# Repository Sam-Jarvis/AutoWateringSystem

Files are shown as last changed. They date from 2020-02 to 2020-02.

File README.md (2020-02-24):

# AutoWateringSystem
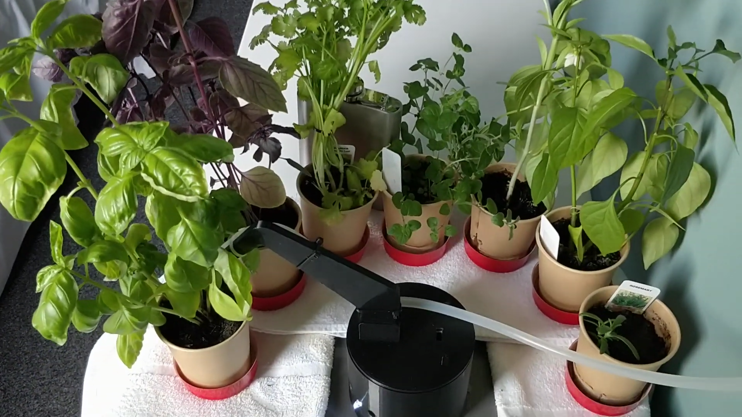
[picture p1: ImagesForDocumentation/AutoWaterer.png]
Image of msn-lsn
<br>
__Video example:__ https://youtu.be/DMxAB1ufoSI<br>

### This repository contains 3D designs, code and a technical report of an automatic plant watering system I built.<br>

The system is designed and built to be run on an arduino, thus it is programmed in C using the Arduino IDE. The purpose of the system is to water herbs or other plants without human interaction. This is based on a timer that can be set by the user. The system can water a set number of plants or it can adapt to the number of plants on the fly given that an ultrasonic sensor is connected.<br>

The parts necessary to build the system are:
* Servo (small)
* Arduino
* Jumper wires
* Ultrasonic sensor (_optional_)
* 9V battery
* Relay
* Aquarium pump

Details of the project can be found in the technical report but to summarize the system, the relay control an aquarium pump that is placed in a reservoir of water. The relay is controlled by the Arduino which is powered by the 9V battery. The time interval between watering is set using the potentiometer.<br>  

The parts are assembled inside the 3D printed base and connected together like this (also in the technical report):
### Circuit Diagram
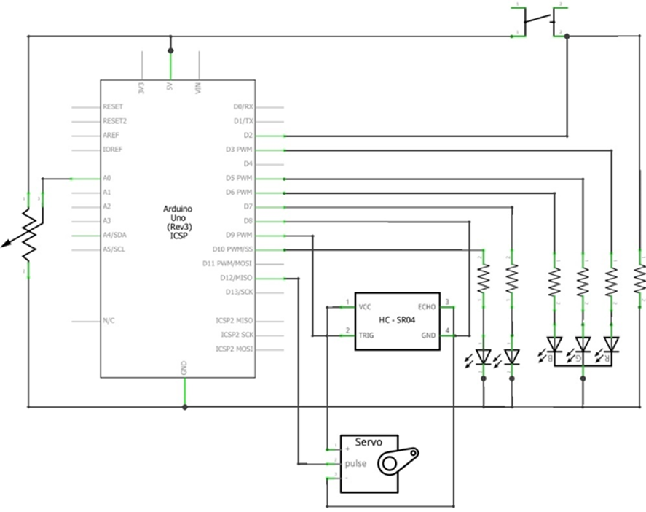
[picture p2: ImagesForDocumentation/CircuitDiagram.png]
Image of msn-lsn
<br>

### Example Circuit
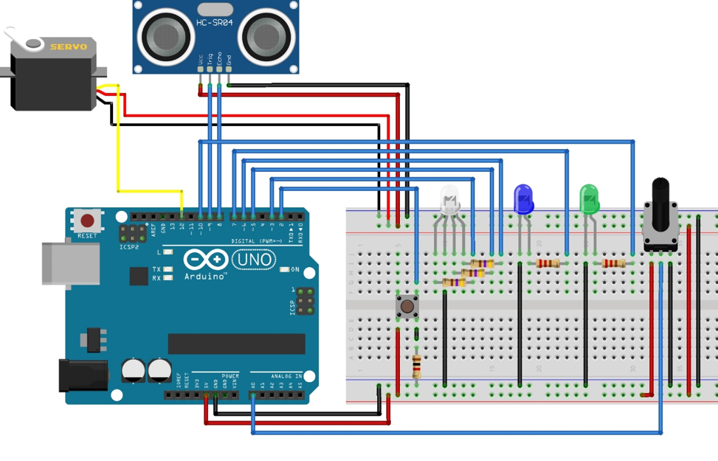
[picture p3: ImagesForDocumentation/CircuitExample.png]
Image of msn-lsn
<br>

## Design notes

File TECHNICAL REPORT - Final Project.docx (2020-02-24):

TECHNICAL REPORT

Auto-Watering System

Embedded Systems (ES1)

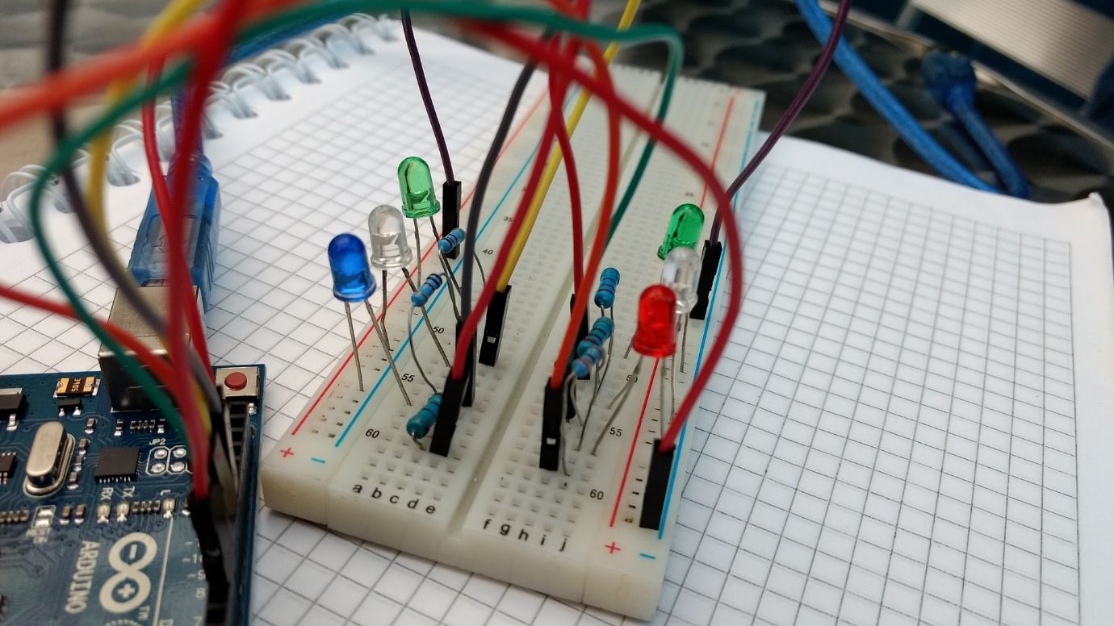
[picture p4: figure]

LECTURER: Gerald Hilderink

DATE: 29-03-2019

AUTHORS: Sam Jarvis - 3734811

Yasser Alhazmi - 405156

Abstract

The week 6 assignment proved more flexible than previous weeks which presented different problems. The goal of the final assignment was to use as many of the components from previous weeks as possible. An auto-watering system was constructed using the following parts: one button, two LEDs, one RGB LED, one potentiometer, one servo and one ultrasonic sensor. Some of the techniques learned were LEDs, buttons, button debounce, potentiometer, RGB, functions, correct scoping, state machines, serial communication, Servo, and ultrasonic sensor.

# Introduction

The auto watering system is the product of the week 6 final assignment. The aim of the assignment was to use as many of the components that featured in previous assignments, as possible. However, the practical purpose of the auto-watering system is to solve a real-world problem. The auto-watering system tends to pot plants with minimal user interaction. This means the user can configure the system as they desire and have little to no interaction with the system thereafter. The problem this system solves is neglection of plants due to more important day-to-day activities.

The system works as follows. When the power button is pressed, the system turns on. A green LED illuminates to visually represent this. If the system is on and the power button is held down, the system and LED turn off. Once on, the arm rotates from 0 degrees to 180 degrees at intervals of 20 degrees. At each iteration, it tries to detect a plant. If a plant is detected, the arm stops rotating, and the blue LED illuminates to simulate the system watering a plant. Once it has repeated this and watered all plants in a semicircle, the system waits for a user selected time. The use can determine this time by changing the value of a potentiometer. If the time is two hours, the system will wait at 180 degrees for two hours before repeating the cycle in reverse. The user selected time is illustrated by an RGB LED. The LED will cycle the RGB spectrum for the user selected time. For example, if the user selected time is two hours, the RGB LED will take two hours to cycle from green to red.

## Procedure

### Apparatus

- 1x breadboard
- 19x male-to-male jumper wires
- 1x Arduino Uno
- 2x LEDs
- 1x RGB LED
- 5x 470-ohm resistor
- 1x button
- 1 x 10kΩ resistor
- 1x potentiometer 1kΩ
- 1x ping sensor
- 1x servo
- 1x 3D printed design

Before starting the assignment, it was necessary to test all the apparatus separately to make sure all hardware was working as expected. To do this, a multimeter was set to the correct mode and connected across each component so that if there was a current present, it would flow through the component and the multimeter. If the multimeter made a beep noise, the component was declared working and was used in the system.

The procedure of this plant watering device is complex. The simplest approach to describe it is to follow the program beginning-to-end. The program begins by including the servo library[^1] and by following the conventions of the C programming language by defining functions above main. It then continues to declare and initialize the constant and global variables of the program. Pins are declared using the “const int” approach rather than the pre-processor directive “#define” because the former is the advised method according to the Arduino programming reference [[^2]]. The servo object is also declared as a global variable. It will be accessed by multiple methods in the program. In the “setup()”[^3] method, all pins were assigned an appropriate mode using the “pinMode()”[^4] method. In addition to this, the servo was attached to the appropriate pin using “Servo.attach()”[^5] method, and serial communication was initiated using “Serial.begin()”[^6]with the default baud rate of 9600.

The machine then enters the “loop()”[^7] method while still in turned off state. In the loop, the program checks whether the button is clicked. This check includes a button debounce function of 70 milliseconds to eliminate any possible bouncing effect. If the button is clicked, the method “turnMachine()” is called to turn the machine on. The method “turnMachine()” will check the “machineIsOn” variable status. If machine is off, the following steps are taken to turn the machine on:

1. Turn the green LED on.
2. Read the potentiometer value. This is to ensure persistence, that is, the user is not required to input the time interval each time the system is started. The value is mapped to hours and saved as a time interval that is later used as a delay.
3. Print that the machine is turned on via serial communication.
4. Change the machineIsOn variable to true.

After the machine is turned on, the program continues to the loop() method. A “while” loop is initiated if machineIsOn is equal to true. In the while loop, the method rotateServo() is called to rotate the servo. This method will start with angle of 0 degrees and rotate by 20 degrees each time the method is called. This is done by calling the servo.write()[^8] method from the servo library and supplying the angle to it as an argument.

After each call (a rotation of 20 degrees has occurred), it calls the method detectPlant() to determine whether the ultrasonic can detect an object (plant). The detectPlant() method uses the ultrasonic sensor to detect an object within the appropriate distance. This code was re-used from a previous assignment[^9]. Based on the 3D design, the appropriate distance for a plant is 4-6 centimetres from the system. If a plant is detected within this distance, the servo will temporarily stop rotating to allow the system to water the plant. The blue LED will turn on to simulate watering.

When the servo reaches an angle of 180 degrees, that is, it’s maximum, it will stop for a certain amount of time before repeating the cycle in reverse. This is done by calling the method delayWatering(). The same method is called when the servo rotates back to an angle of 0, that is, it’s minimum. The amount of delay time between cycles is changed as follows:

1. The initial value of the potentiometer is read and mapped to a time in milliseconds when the device is turned on.
2. The current value of the potentiometer is read after each servo rotation in case the user changes the state of the potentiometer.
3. If the current value is equal to initial value, no action is taken.
4. If the current value is not equal to initial value, the initial value is changed to the current value.
5. This value is used as the amount of time to wait between watering cycles.

To convert the value read from the potentiometer to a value of time in milliseconds, the following steps are taken:

1. The potentiometer reading is mapped from a value between 0 and 1023, to a value between 1 and 12. Thus, the user can specify a time interval between 1-12 hours to wait in between each watering cycle.
2. The mapped value is converted to milliseconds by the equation: delayTime = mappedValue * 60 * 60 * 1000. To further explain, a value between 1 and 12 is multiplied by 60 to convert it from hours to minutes. This is converted to seconds by multiplying by 60 again and finally, it is multiplied by 1000 to convert it to milliseconds. The reason for this is so that the native “delay()” method can be used.
3. To cycle through the RGB spectrum (from green to red) while waiting, the delay time is divided by the number of values in the spectrum (256 to include the 0). This provides the delay in milliseconds that the Arduino must wait before changing the RBG value. This is done in a method called “delayWatering()”.

The “delayWatering()” method will initialize the green colour channel of the RGB LED to 255 and red, blue, and counter to zero, because it will only cycle the spectrum after watering is finished. After the appropriate delay, green will decrease by one, red will increase by one, and counter will increase by one as well. The method “changeRgbByValue()” is re-used from a previous assignment, and it changes the value of an RGB LED based on three integers values red, green, and blue. The method loops until the counter reaches 255. At this point, red will be 255 and green will be zero. The loop will terminate because the delay time has ended, and the system will induce another cycle. That is, the servo will start rotating to water the plants again.

# Design and Construction

The system consists of three main parts namely, the physical body, the circuit and electronics and the software written in C. Each of these categories has a design aspect which is described in detail below.

## Body

The body of the system was specific to its purpose and thus had specific requirements. For example, the upper section had to rotate using the servo. So, the upper section needed a bed for the servo rudder to rest in. For this reason, the parts were designed using measurements from the electronic components and 3D printed.

The body consisted of the following parts:

1. The base.

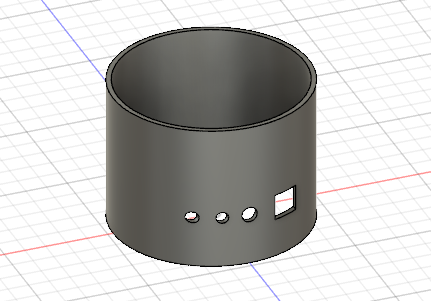
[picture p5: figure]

Figure 1 illustrates the 3D design of the base. This is the container for the system and has the required fittings for the potentiometer, two LEDs and the button. This is the biggest component because it is the structural integrity of the system.

2. The Lid

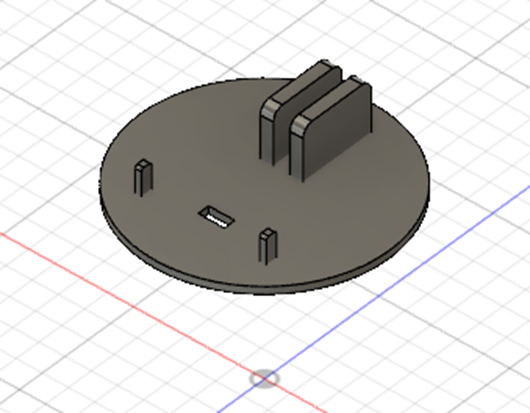
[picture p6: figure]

Figure 2 illustrates the lid of the system. The lid is the component between the solid foundation and the rotating section of the system. The lid has fittings designed for the ultrasonic sensor. It has a bay for the ultrasonic sensor to rest in as well has a space for its wires to connect through.

3. The Arm

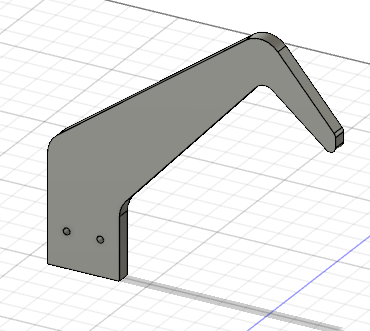
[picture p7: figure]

Figure 3 illustrates the arm. This connects to the lid and is responsible for watering the plants. The arm has two screw holes to secure it to the lid.

4. The Servo Bay

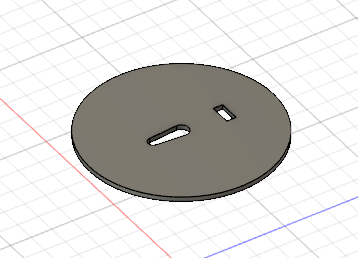
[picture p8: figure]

Figure 4 illustrates the servo bay. This component is responsible for attaching the lid to the base such that the lid can rotate whilst the base does not. It has fittings for the servo rudder and a space for the ultrasonic sensor wires. It is fixed to the underside of the lid such that the space for the ultrasonic sensor wire align.

## Circuit

The circuit represents the electrical components and how they are connected to the Arduino. The Schematic diagram of the circuit can be found below.

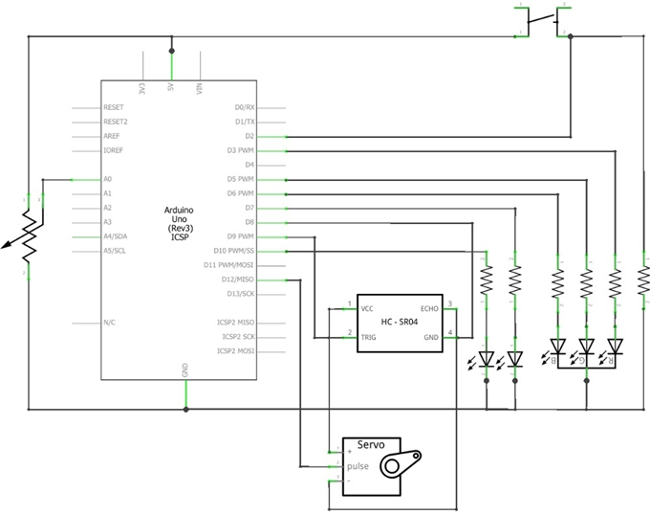
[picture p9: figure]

Figure 5 illustrates how the components are connected to the Arduino. All components have a live and ground connection. Each RGB channel is connected to a separate pin. The servo is connected to pin 12, the ultrasonic sensor is connected to pins 8 and 9, the potentiometer is connected to pin A0, the normal LEDs are connected to pins 10 and 7 and finally, the RGB LED is connected to pins 3, 5 and 6.

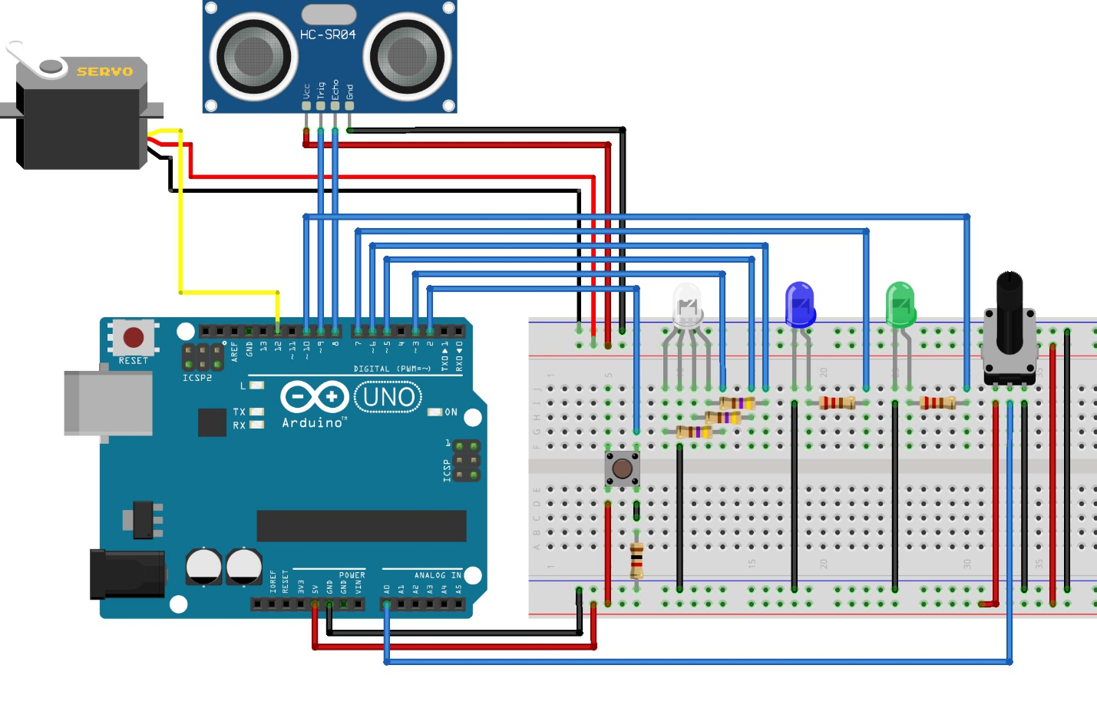
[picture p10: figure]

Figure 6 illustrates a graphical example of the components connected to the Arduino.

## Software

The software aspect of the system features under the design section due to the state machine ideology that is embedded within it. Each function that the system offers is a separate state in the software. For example, when the Arduino is plugged in, but the power button has not been pressed, it is in the “turned off” state.

The state diagram of the system is presented below:

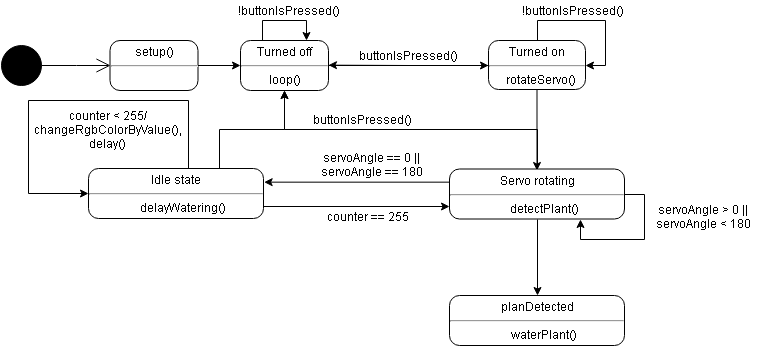
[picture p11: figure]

Figure 7 describes the state machine of the system. On initialization, the system is in the turned off state. When the power button is pressed, the state is changed to “Turned On”. From the “Turned On” state, the system proceeds to the “Servo Rotating” state, unless the user presses the power button. In this case, the state is changed to “Turned Off”. In the “Servo Rotating” state, the system will proceed into the “Plant Detected” state if a plant is detected. If no plant is detected, the system remains ins the “Servo Rotating state” if the servo angle is less than 180 degrees. Once this condition is false, the system will move into the “Idle” state where it will remain until the counter is 256. At this point it will return to the “Servo Rotating” state. It is also possible for the system to go from the Idle state to the “Turned Off” state should the user press the power button.

# References

Some of the components and techniques used required some research first. Below is a list of all the resources used to complete this assignment.

[^1] https://www.arduino.cc/en/Reference/Servo
[^2] https://www.arduino.cc/reference/en/language/structure/further-syntax/define/
[^3] https://www.arduino.cc/reference/en/language/structure/sketch/setup/
[^4] https://www.arduino.cc/reference/en/language/functions/digital-io/pinmode/
[^5] https://www.arduino.cc/en/Reference/ServoAttach
[^6] https://www.arduino.cc/en/serial/begin
[^7] https://www.arduino.cc/en/Reference/Loop (https://www.arduino.cc/en/Reference/Loop?setlang=it)
[^8] https://www.arduino.cc/en/Reference/ServoWrite
[^9] http://www.robot-electronics.co.uk/htm/arduino_examples.htm#SRF04%20Ultrasonic%20Ranger 10 https://www.youtube.com/watch?v=_B3gWd3A_SI&t=95s

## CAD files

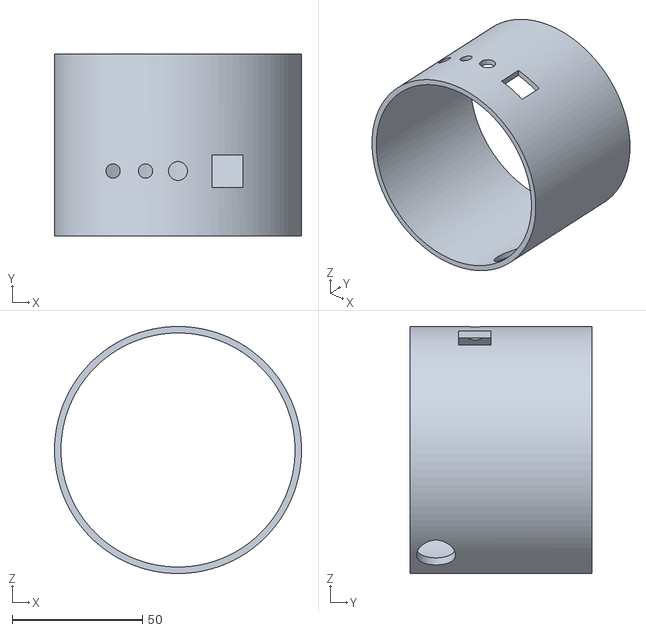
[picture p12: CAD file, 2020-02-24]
3D designs/base.stl
95.0 x 70.0 x 95.0

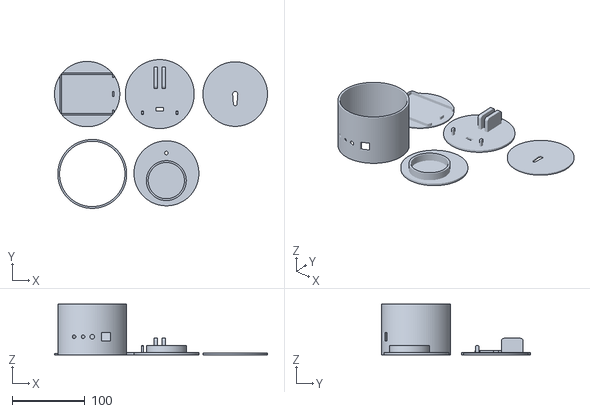
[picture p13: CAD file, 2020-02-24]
3D designs/ES1_Week6_Version3.stl
293.5 x 205.0 x 70.0

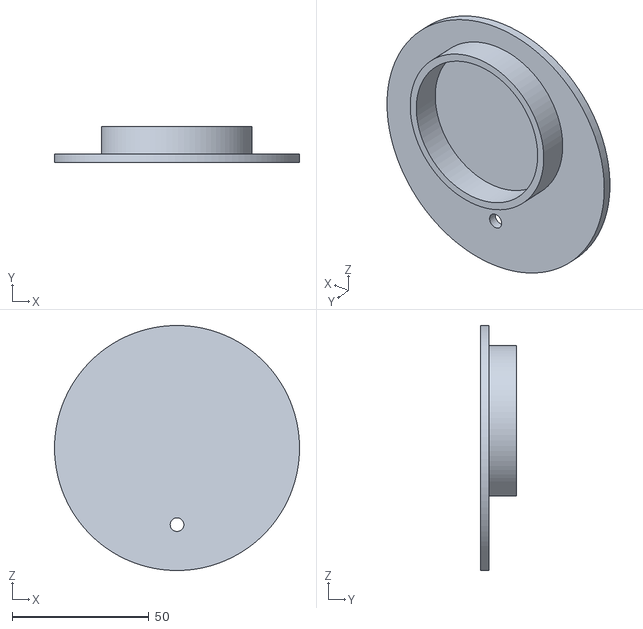
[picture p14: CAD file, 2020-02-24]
3D designs/servo_base.stl
89.5 x 13.0 x 89.5

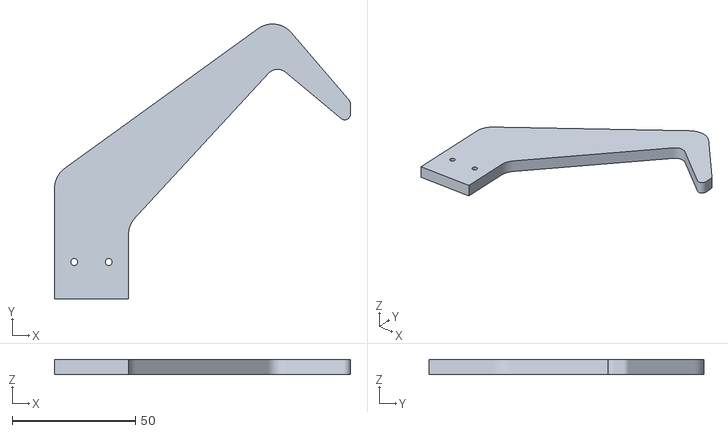
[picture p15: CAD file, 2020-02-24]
3D designs/arm.stl
120.0 x 111.5 x 6.00

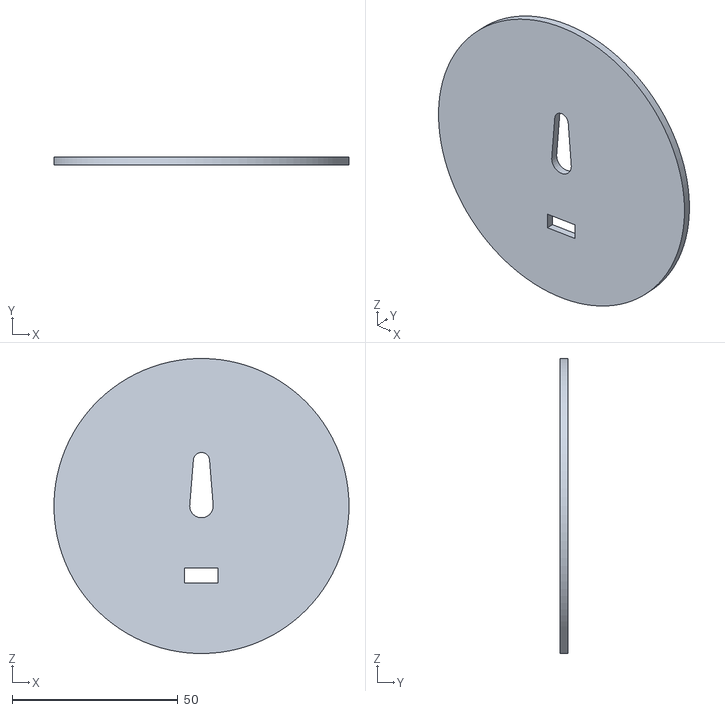
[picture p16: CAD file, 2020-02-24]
3D designs/servo_bay.stl
89.0 x 2.30 x 89.0

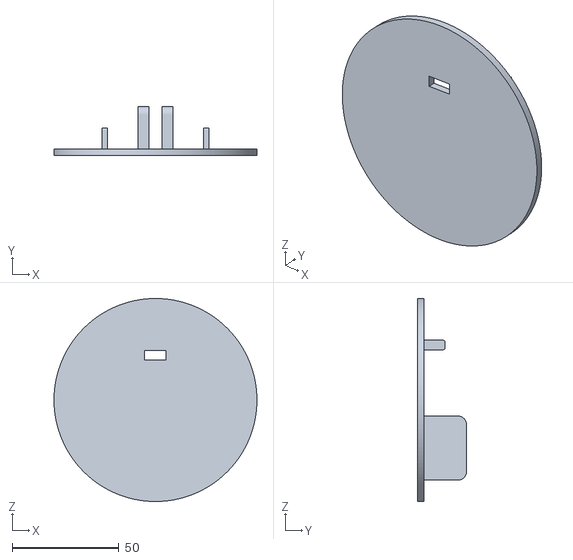
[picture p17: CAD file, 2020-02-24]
3D designs/lid.stl
95.0 x 23.0 x 95.0

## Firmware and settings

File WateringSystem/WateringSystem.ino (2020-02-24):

/*********************************************************
* ES1 Week 6 and 7 Assignment
*
* Course : Embedded Systems 1 (ES1)
* Assignment: ES1 Final Project Assignment
* Date : 1-04-2019
* Student(s) : Sam Jarvis (3734811)
*              Alhazmi Yasser (3529495)
*
*********************************************************/
#include <Servo.h>

/*** Function declarations ***/

//Turn the machine on or off based on the boolean machineIsOn
void turnMachine();

//Button debounce that takes the button pin number and debounce time in milliseconds as arguments
boolean buttonIsPressed(int, int);

//Rotate the servo and with every rotation invoke detectPlant()
void rotateServo();

//Use PING to detect if a plant exist
void detectPlant();

//Check if the user changed the watering time interval and set the new interval if necessary
void checkTimeInterval(int);

//Convert the potentiometer mapped value to milliseconds
long int hourToMilliSeconds(int);

//Change the RGB LED color based on passed value
void changeRgbColorByValue(int, int, int)

/*** PINS and Program Constants ***/
//Potentiometer PIN
const int POTENTIOMETERPIN = A0;

//Button pin
const int BUTTONPIN = 2;

// Blue channel pin (on the LED)
const int BLUEPIN = 6;

// Green channel pin (on the LED)
const int GREENPIN = 5;

// Red channel pin (on the LED)
const int REDPIN = 3;

//LED Pins
const int LEDPINHIGH = 10;
const int WATERINGLED = 7;

//Servo pin
const int SERVOPIN = 12;

//Ping ECHO pin
const int ECHOPIN = 8;

//Ping TRIGGER pin
const int TRIGPIN = 9;

//debounce time for the debounce functions
const int debounceTime = 70;

/*** Global variables ***/

//To determine the machine state
boolean machineIsOn;

//Time to wait after one watering round
int timeInterval;

//Servo object to control the servo
Servo myservo; 


void setup() {
  //LEDs, button, and potentiometer are set to the appropriate pinMode
  pinMode(BUTTONPIN, INPUT); 
  pinMode(LEDPINHIGH, OUTPUT);
  pinMode(WATERINGLED, OUTPUT);
  pinMode(POTENTIOMETERPIN, INPUT);

  //PING sensor
  pinMode(ECHOPIN, INPUT);
  pinMode(TRIGPIN, OUTPUT);

  //RGB LED channels
  pinMode(BLUEPIN, OUTPUT);
  pinMode(GREENPIN, OUTPUT);
  pinMode(REDPIN, OUTPUT);

  //Sevo
  myservo.attach(SERVOPIN);  // attaches the servo on pin 9 to the servo object

  //Serial
  Serial.begin(9600);
}

void loop() {

  // Turn machine on if button is pressed
  if (buttonIsPressed(BUTTONPIN, debounceTime)) { //Turn the machine ON
    turnMachine();
  }

  delay(50);

  //If machine is turned on, start looking for plants to water
  while (machineIsOn) {
    rotateServo();
    if (buttonIsPressed(BUTTONPIN, debounceTime)) {
      //If button is cliked and machine is on, turn it off
      if (machineIsOn) {
        turnMachine();
        return;
      }
    }

}
}// end loop()



//Check if the user changed the watering time interval and set the new interval if necessary
void checkTimeInterval(int oldTimeInterval) {
  int checkTimeInterval = map (analogRead(POTENTIOMETERPIN), 0, 1023, 1, 12); //obtain a new read and map it
  if (checkTimeInterval != oldTimeInterval) { //If the user changed watering interval
    timeInterval = checkTimeInterval;   //Update the watering interval
    Serial.print("New read: ");   //Print the new value
    Serial.println(checkTimeInterval);  //Print the new value
  } else {
    Serial.println("Potentiometer value not changed");
  }
  if (buttonIsPressed(BUTTONPIN, debounceTime)) {
    if (machineIsOn) {
      turnMachine();
      return;
    }
  }
  delay(100);
}


//Rotate the servo and with every rotation invoke detectPlant()
void rotateServo() {
  static int i = 0; // The current angle of the servo
  static boolean TurnOpposite = false; //Turn to the opposite direction if true
  while (machineIsOn) {
    if (i >= 180) {
      TurnOpposite = true;
      delayWatering(); //we have watered all the plants, now we wait for the interval the user specified before watering again
    }
    else if (i == 0) {
      TurnOpposite = false;
      delayWatering(); //we have watered all the plants, now we wait for the interval the user specified before watering again
    }

    if (TurnOpposite == true) {
      i -= 20; //Set the degrees by which the servo will move 
    }
    else if (TurnOpposite == false) {
      i += 20; //Set the degrees by which the servo will move 
    }
    myservo.write(i); //Move the servo
    if (buttonIsPressed(BUTTONPIN, debounceTime)) {
      if (machineIsOn) {
        turnMachine();
        return;
      }
    }
    //servo is moved, let's see if we can find a plant
    checkTimeInterval(timeInterval);
    detectPlant();
  }
}

void detectPlant() {

  int MindistanceToPlant = 4, distance, MaxDistanceToPlant = 6; //define minimun and maximum distances in cms
  
  digitalWrite(TRIGPIN, LOW);                   // Set the trigger pin to low for 2uS
  delayMicroseconds(2);
  digitalWrite(TRIGPIN, HIGH);                  // Send a 10uS high to trigger ranging
  //Calibrate this for better detection
  delay(1000);
  digitalWrite(TRIGPIN, LOW);                     // Send pin low again

  distance = pulseIn(ECHOPIN, HIGH);        // Read in times pulse
  distance = distance / 58;                     // Calculate distance from time of pulse
  Serial.println(distance);

  if (distance >= MindistanceToPlant && distance <= MaxDistanceToPlant ) {
    //Watering. Let's turn the internal LED on for now
    digitalWrite(WATERINGLED, HIGH);
    //digitalWrite(WATERINGLOW, LOW);
    delay(2000);
    digitalWrite(WATERINGLED, LOW);
  } else {
    digitalWrite(WATERINGLED, LOW);
  }
  if (buttonIsPressed(BUTTONPIN, debounceTime)) {
    if (machineIsOn) {
      turnMachine();
      return;
    }
  }
}


void turnMachine() {
  if (!machineIsOn) {
    timeInterval = map(analogRead(POTENTIOMETERPIN), 0, 1023, 1, 12); //Initial read (from previous setup) of the timing interval
    Serial.println("Machine state: ON");
    machineIsOn = true;
    digitalWrite(LEDPINHIGH, HIGH); //Turning green LED on
    delay(200);
    return;
  }
  //The machine should be turned off
  Serial.println("Machine state: OFF");
  machineIsOn = false;
  //Turn all LEDs off
  changeRgbColorByValue(LOW, LOW, LOW);  
  digitalWrite(LEDPINHIGH, LOW);
  digitalWrite(WATERINGLED, LOW);
  delay(200);
  
}

long int hourToMilliSeconds(int hour) { //Hour is the mapped potentiometer value
  long int convertedTime = hour * 60 * 60 * 1000;
  Serial.print("Time in hours is: ");
  Serial.print(hour);
  Serial.print(". This is ");
  Serial.print(convertedTime);

  return convertedTime;
}

//Watering will be delayed by the given time interval
void delayWatering()
{
  int red = 0;
  int blue = 0;
  int green = 255;
  int counter = 0;
  long int delayTime = hourToMilliSeconds(timeInterval / 255); //Time to wait is divided by the RGB color spectrum to take x time to move from green to red

  while (counter <= 255)
  {
    counter++;
    green -= 1;
    red += 1;
    changeRgbColorByValue(red, green, blue);
    delay(delayTime);
    if (buttonIsPressed(BUTTONPIN, debounceTime)) {
      turnMachine();
      return;
    }
  }
}

//Change the RGB LED color based on passed value
void changeRgbColorByValue(int rValue, int gValue, int bValue)
{
  analogWrite(REDPIN, rValue);
  analogWrite(BLUEPIN, bValue);
  analogWrite(GREENPIN, gValue);
  delay(50);
}


boolean buttonIsPressed(int BUTTONPIN, int debounceCheckTimeMilliSeconds)
{
  if (digitalRead(BUTTONPIN) == LOW)
  {
    return LOW;
  }
  delay(debounceCheckTimeMilliSeconds);
  if (digitalRead(BUTTONPIN) == HIGH)
  {
    return HIGH;
  }
  return LOW;
}

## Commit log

2020-02-24 complete project
    [ES1_Week6_Version3.stl, arm.stl, base.stl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]
2020-02-24 added circuit diagram images for documentation
